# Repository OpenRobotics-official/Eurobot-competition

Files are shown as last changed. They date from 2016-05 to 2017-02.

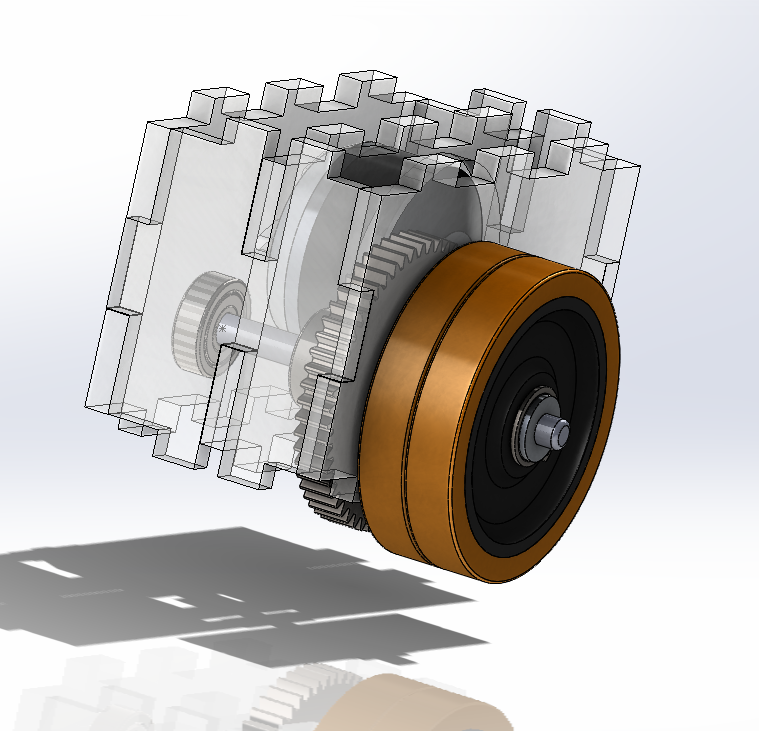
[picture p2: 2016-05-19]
wheelbase/Photo/wheelbase.PNG

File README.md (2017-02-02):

# Eurobot-competition

We are a team of 9 students from ECE Paris school of Engineering, building an Open Source platform for competition robots. We attended Eurobot France, Germany and UK.

## Usage and translation

As the license states, you can do anything you want with our files. We are in the process of checking the good translation of all files, so if you do not understand something, please message us.

## Instructions and logs

You can see how we did our project on our Hackaday.io [project](http://past.is/atcrt/). If you need any helpin using our files, feel free to contact us, **preferably on our hackaday project page**. It's one of our first Robotics project and it is far from perfect so we will be glad to hear some advice and criticism from any other teams.

### IRL - In Real Life

This is mostly meant to be a media for other teams to see what we have done in order to understand us and maybe help us at some competitions like the Île-de-France robotics cup. Feel free to ask questions and contact us IRL!

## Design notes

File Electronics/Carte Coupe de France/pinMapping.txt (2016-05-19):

composant	pin comp	pin arduino

stepper gauche	dir		41
		step		43

stepper droite	dir		37
		step		39

led red		+		52

lcd		data7		45
		data6		47
		data5		49
		data4		51
		enable		53

dip switch	1		36
		2		38
		3		40
		4		42

encodeur bas	X		21
		A		20
		B		19

encodeur haut	X		18
		A		2
		B		3

capteur		1		A5
		2		A4
		3		A3
		4		A2
		5		A1
		6		A0

servo-moteur	1		9
		2		10
		3		11
		5		13

Virage 90deg: 365 steps

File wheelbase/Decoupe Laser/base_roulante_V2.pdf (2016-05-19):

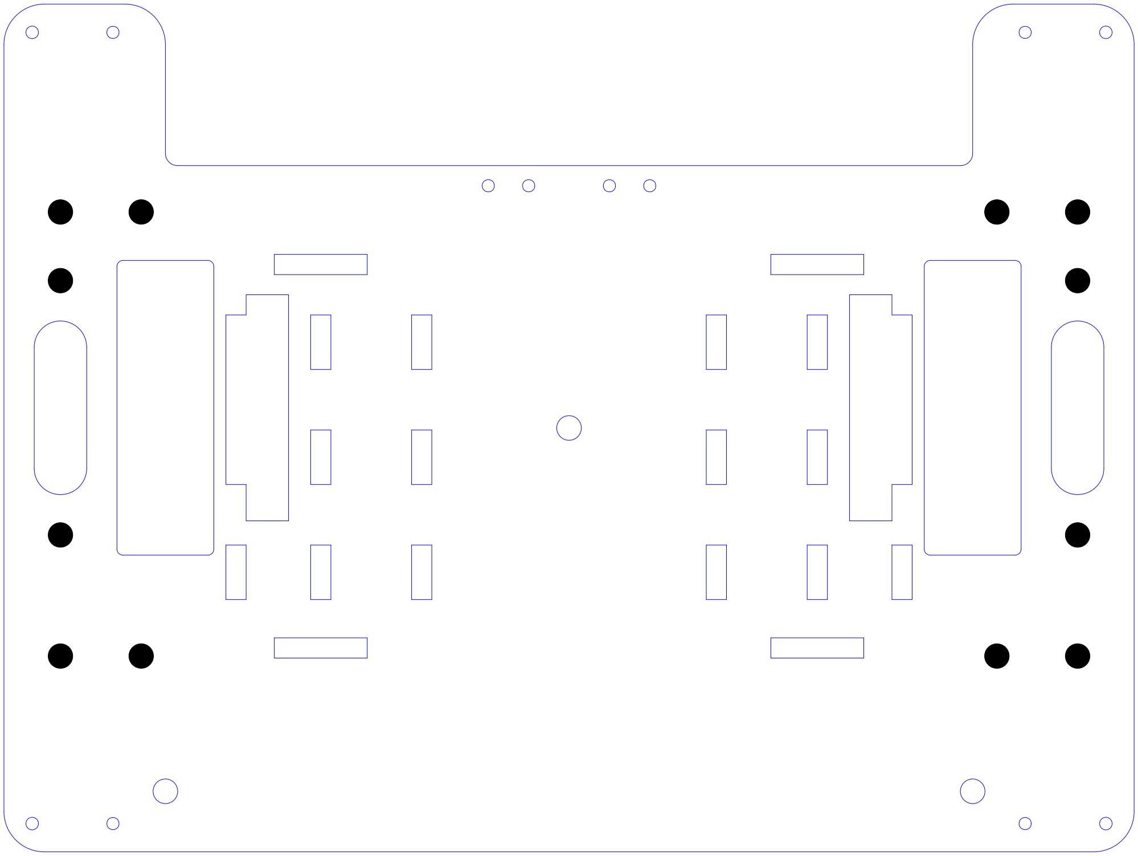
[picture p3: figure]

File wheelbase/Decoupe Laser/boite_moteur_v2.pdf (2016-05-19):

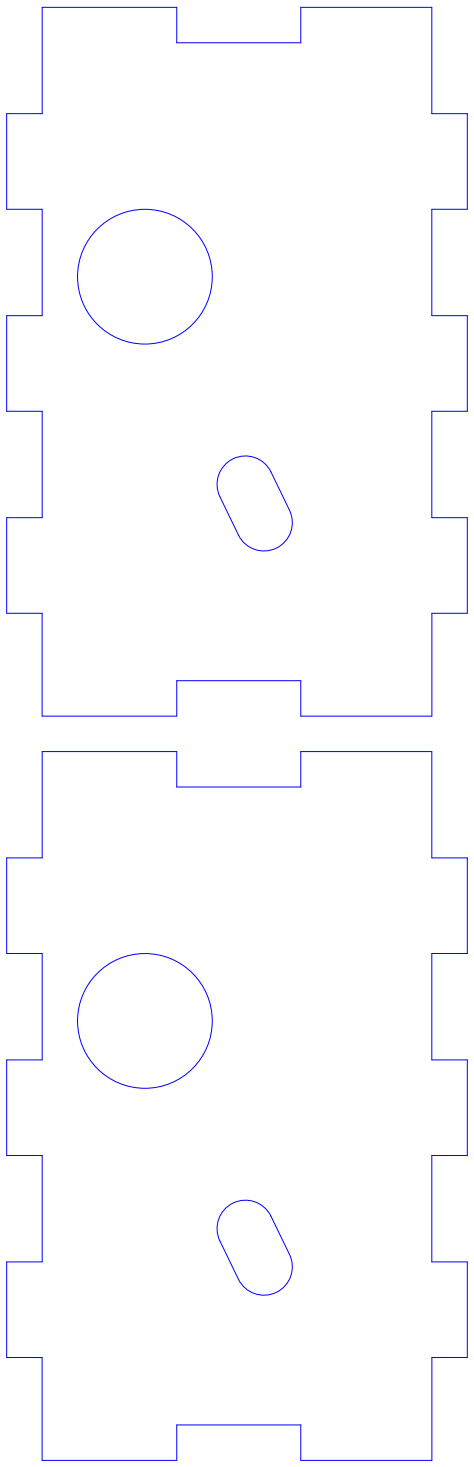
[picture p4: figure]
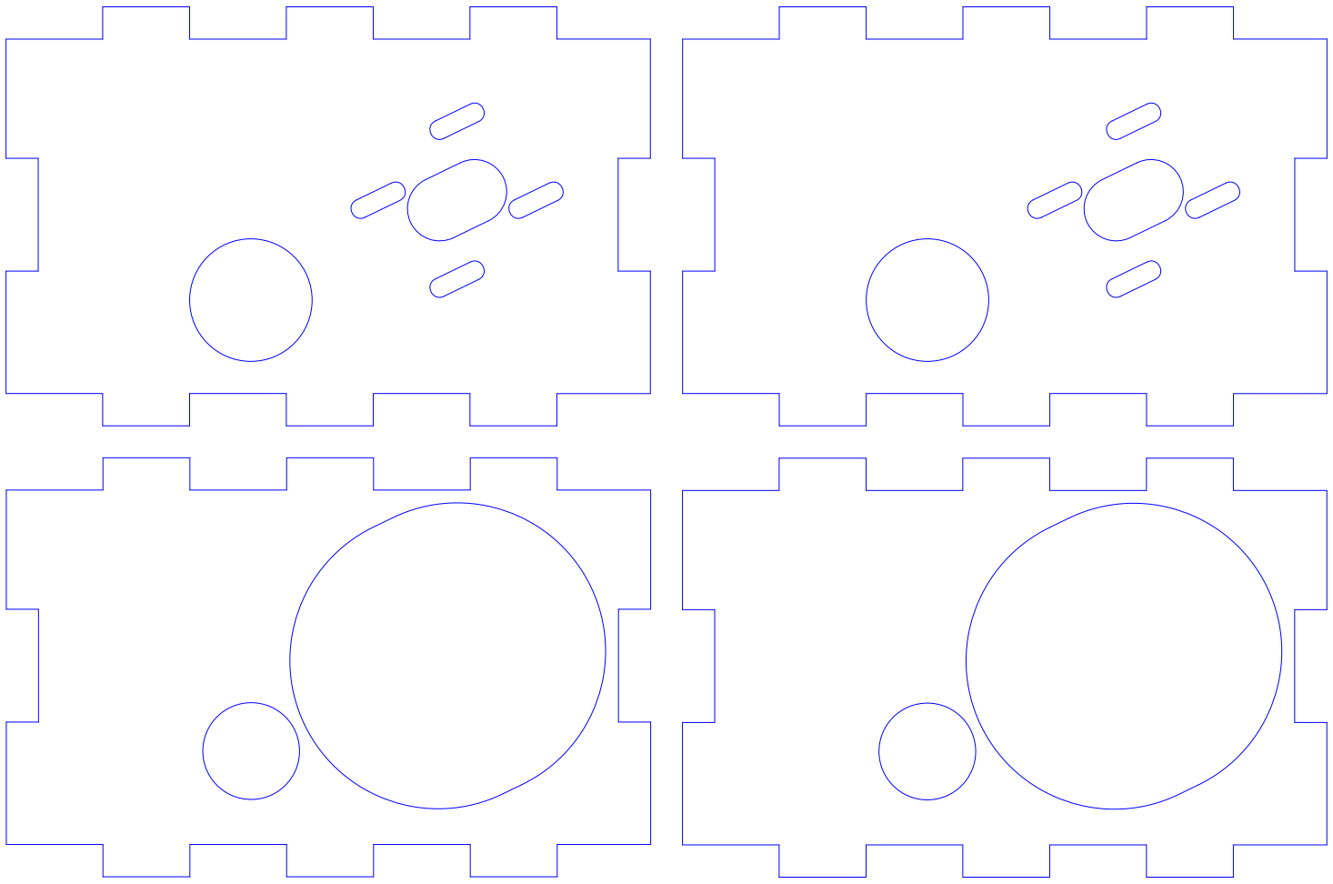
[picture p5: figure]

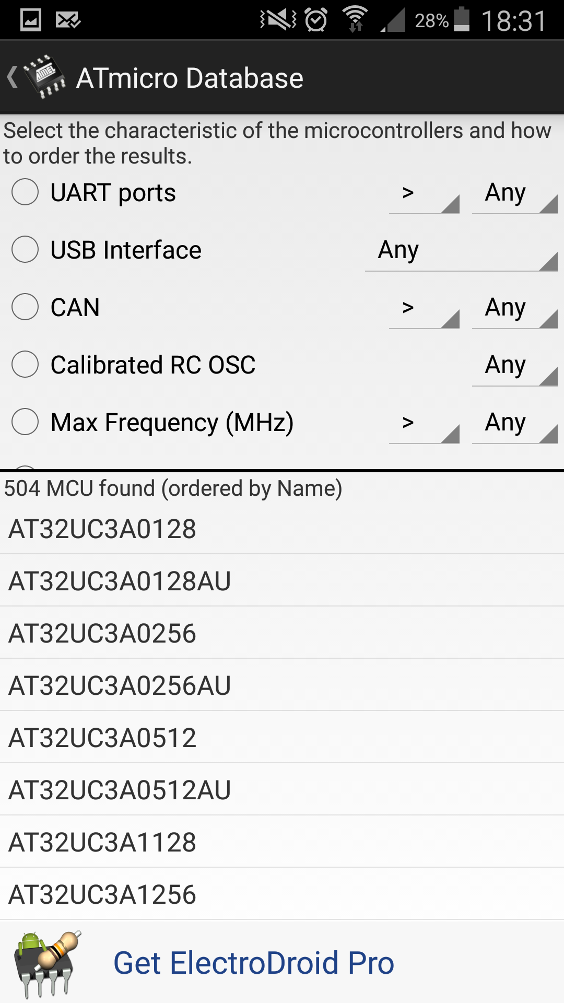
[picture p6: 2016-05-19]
Electronics/Microcontrôleur/Screenshot_2015-12-03-18-31-41.png

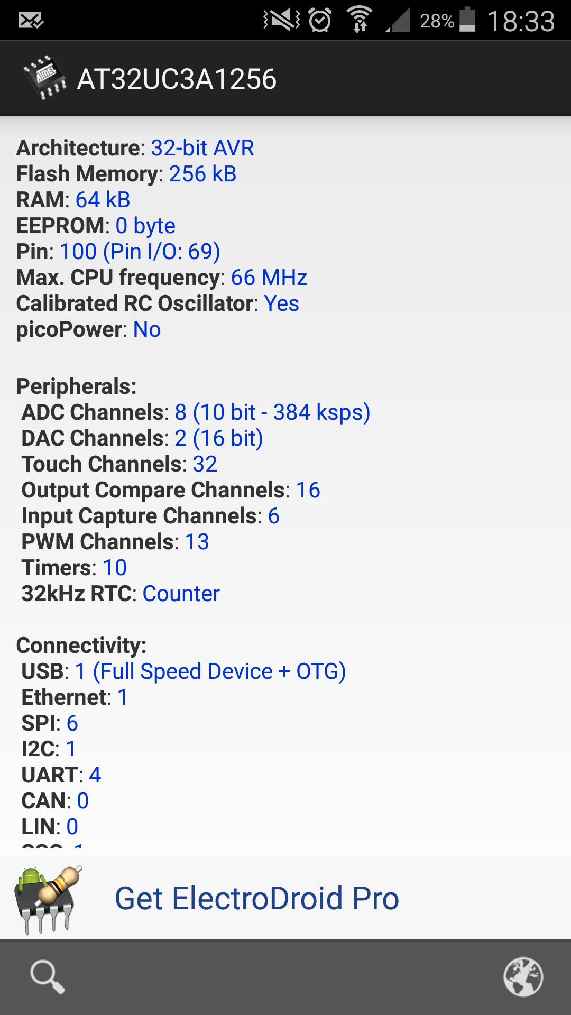
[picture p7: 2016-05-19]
Electronics/Microcontrôleur/Screenshot_2015-12-03-18-33-21.png

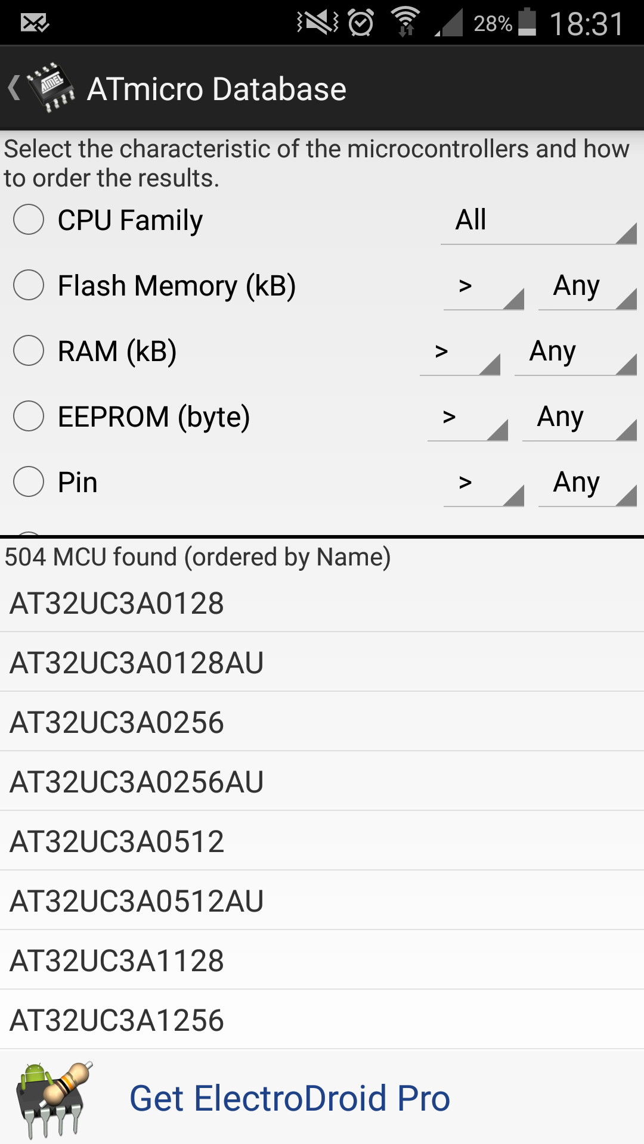
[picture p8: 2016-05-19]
Electronics/Microcontrôleur/Screenshot_2015-12-03-18-31-28.png

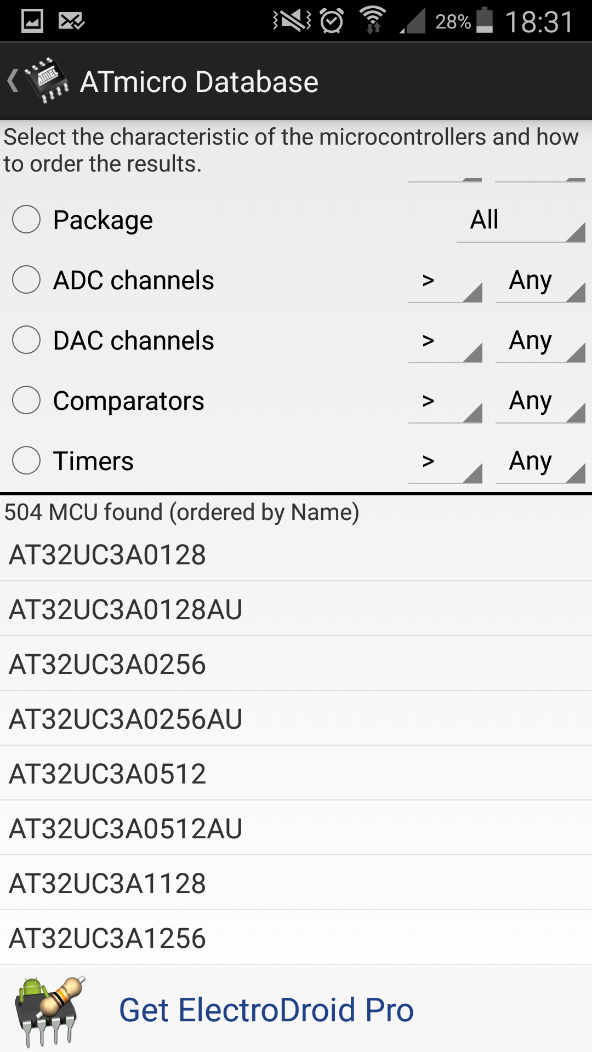
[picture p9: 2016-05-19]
Electronics/Microcontrôleur/Screenshot_2015-12-03-18-31-35.png

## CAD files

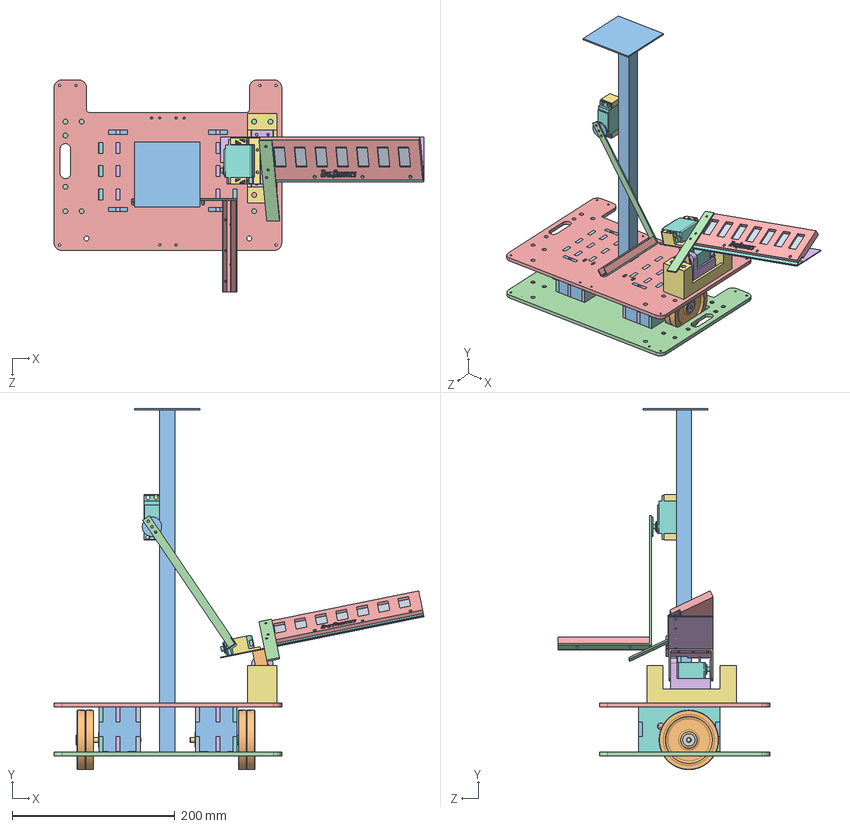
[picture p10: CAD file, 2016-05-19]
assembly_robot.SLDASM
454.7 x 444.0 x 261.1 mm
cote_support_moteur_fin x 2
outside ball bearing 6.6.19 x 6
inside ball bearing 6.6.19 x 6
Quanum360 base x 2
Quanum360 Cage x 2
cote_long_milieu x 2
tige-roue x 2
cote_long_roue x 2
T40H-SM62 x 2
BaneBots_T40 x 4
cote-court_50 x 4
base_dessous_V2_
base_dessus_V2_
Support_bras_base
Support_bras_bloc
Servo x 3
Support_bras_roulement
Support_bras_axe_rotatif
Accessoire_servo_rondelle x 2
Plaquette
Plaque_support_aimant
Plaque_support_poisson
support_servo x 2
Element_Charniere_metal x 2
Aimant x 7
inside_link_bearing
Profile_alu
Bar_angle
Bar_U

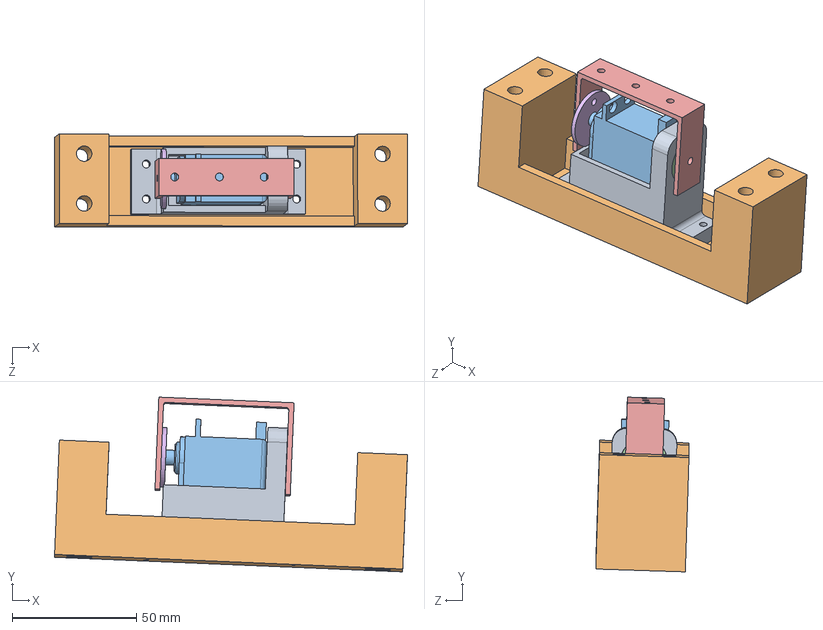
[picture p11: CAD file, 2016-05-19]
Fishing arm/Support_Bras.SLDASM
141.8 x 70.2 x 37.5 mm
Support_bras_base
Support_bras_bloc
Servo
Support_bras_roulement
Support_bras_axe_rotatif
Accessoire_servo_rondelle
inside_link_bearing

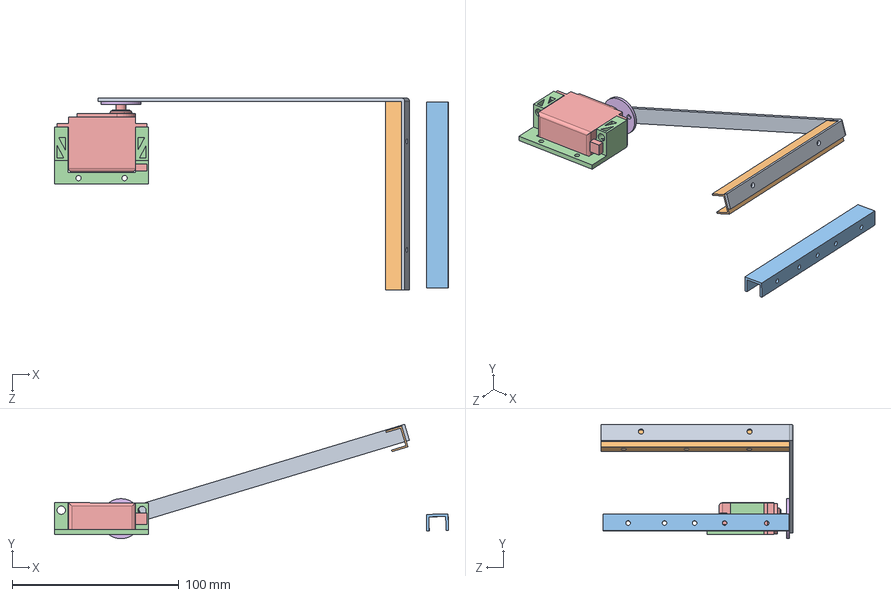
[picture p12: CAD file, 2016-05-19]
Funny action/Parasol_v2/Parasol_v2.SLDASM
236.0 x 68.5 x 115.0 mm
Bar_angle
Bar_U
Bar_u_robot
support_servo
Servo
Accessoire_servo_rondelle

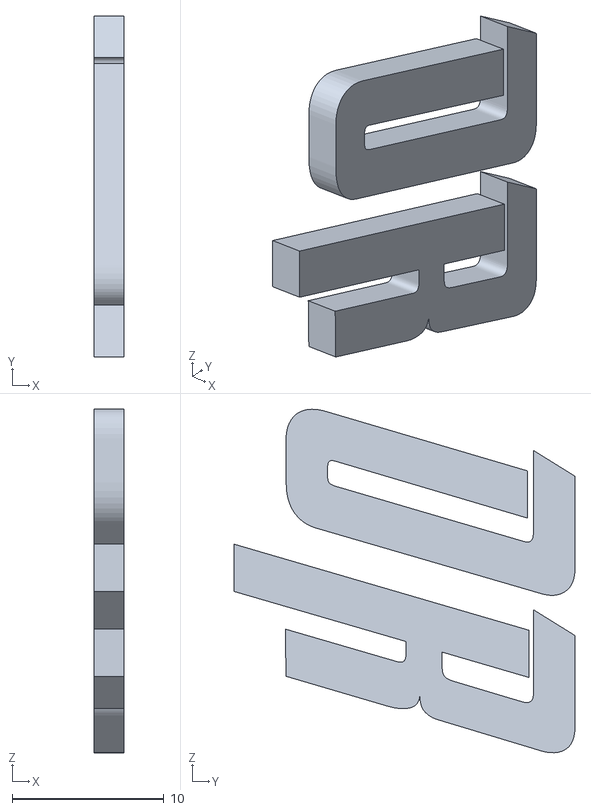
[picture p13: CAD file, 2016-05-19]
wheelbase/solidworks/STL/Assemblahe_base_stepper_logo - OR_logo_72_2mm-1.STL
2.00 x 22.5 x 22.7

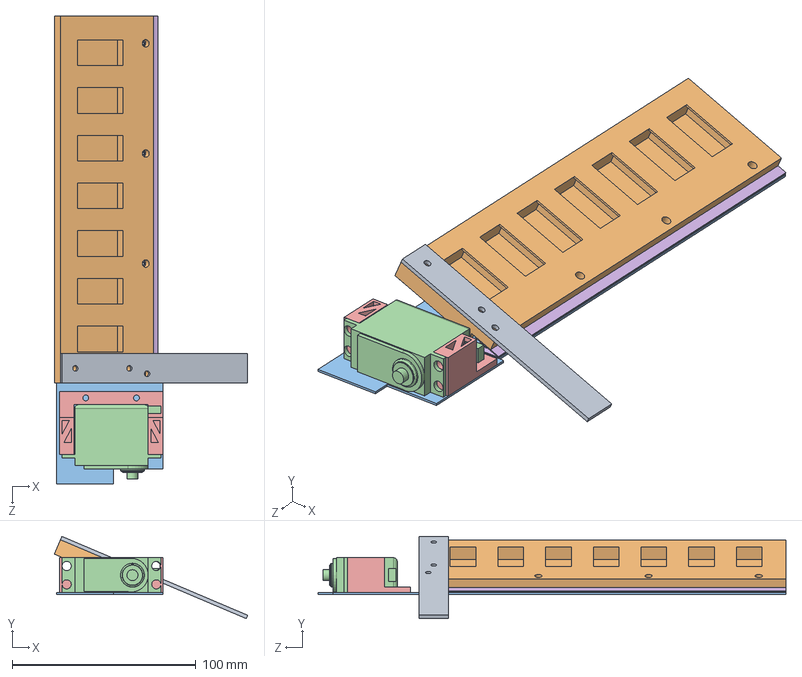
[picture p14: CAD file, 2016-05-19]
Fishing arm/Plaque_aimantée.SLDASM
105.4 x 44.8 x 255.0 mm
Plaquette
Plaque_support_aimant
Plaque_support_poisson
Servo
support_servo
Element_Charniere_metal x 2

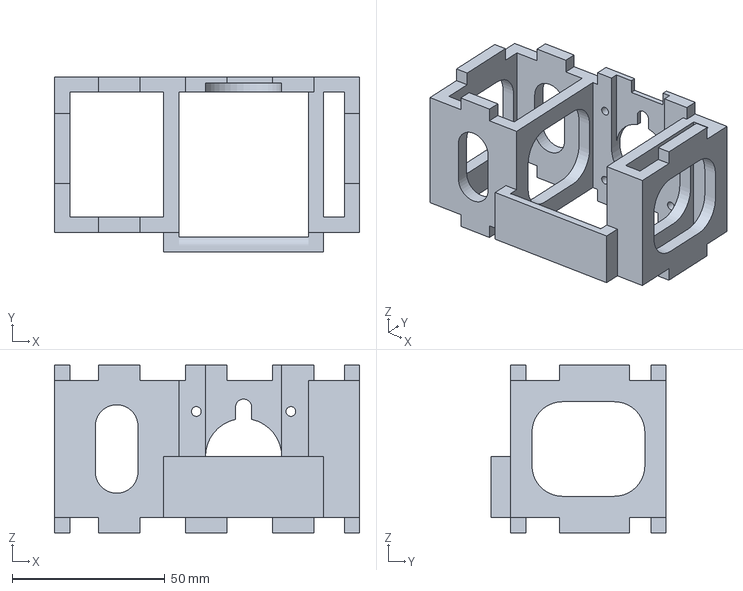
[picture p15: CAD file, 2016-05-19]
wheelbase/solidworks/STL/Assemblage_base_stepper_s3d.AMF
100.0 x 57.5 x 55.0 mm

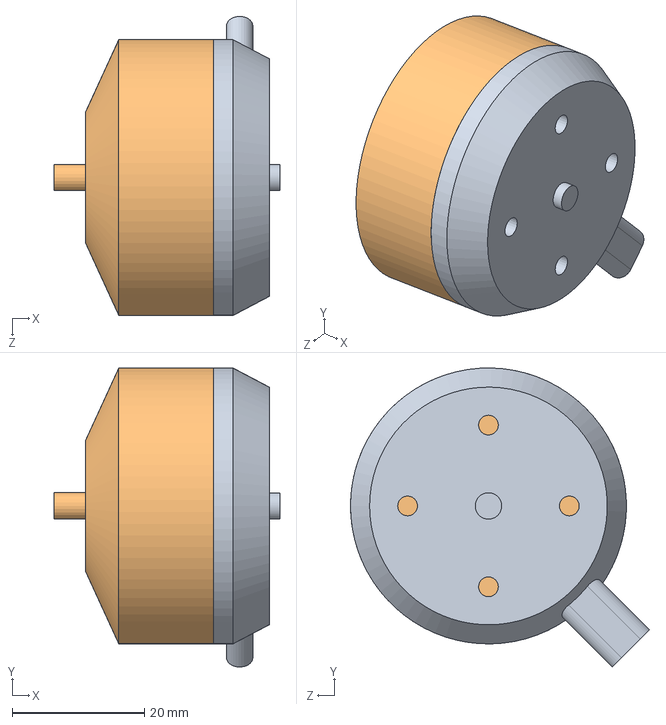
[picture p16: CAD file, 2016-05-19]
wheelbase/solidworks/Quanum motor.SLDASM
34.2 x 45.3 x 45.3 mm
Quanum360 base
Quanum360 Cage

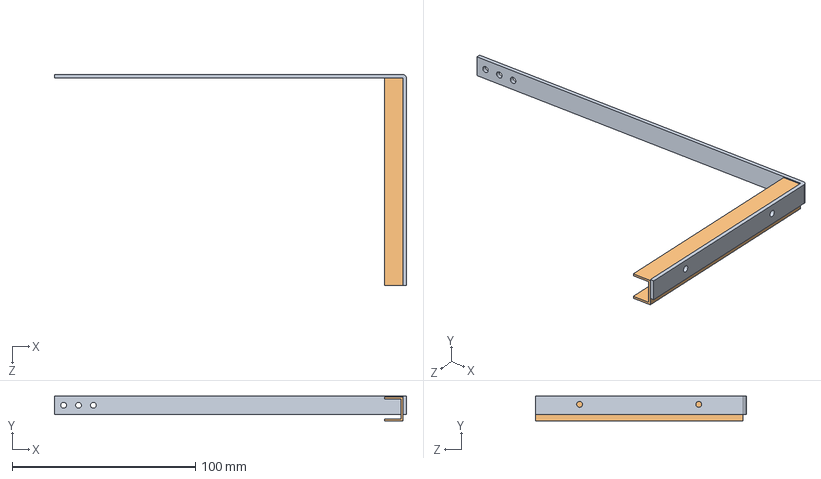
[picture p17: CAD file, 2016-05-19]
Funny action/Parasol_v2/Bras_principal_parasol.SLDASM
192.0 x 13.5 x 115.0 mm
Bar_angle
Bar_U

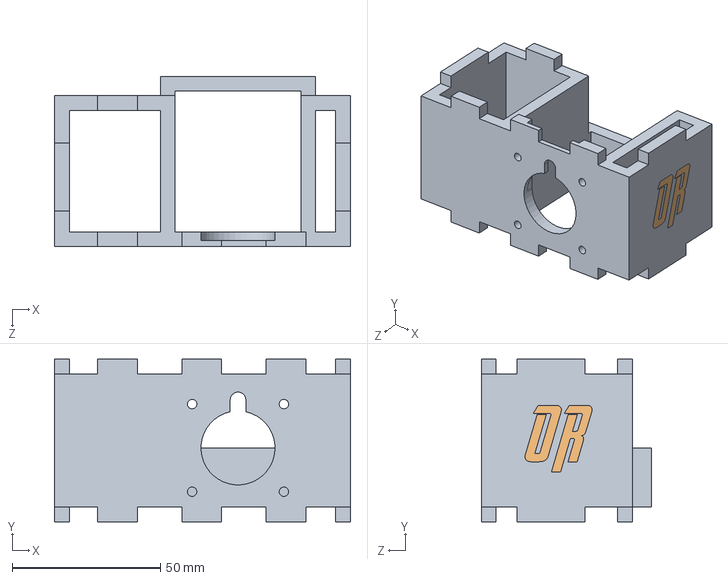
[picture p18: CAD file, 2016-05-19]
wheelbase/solidworks/Assemblahe_base_stepper_logo.SLDASM
100.0 x 55.0 x 57.5 mm
base_stepper
OR_logo_72_2mm

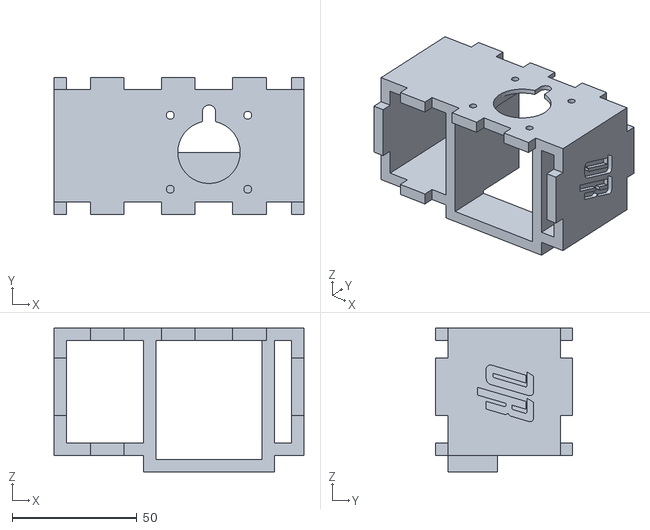
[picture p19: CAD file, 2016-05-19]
wheelbase/solidworks/STL/Assemblahe_base_stepper_logo - base_stepper-1-1.STL
100.0 x 55.0 x 57.5

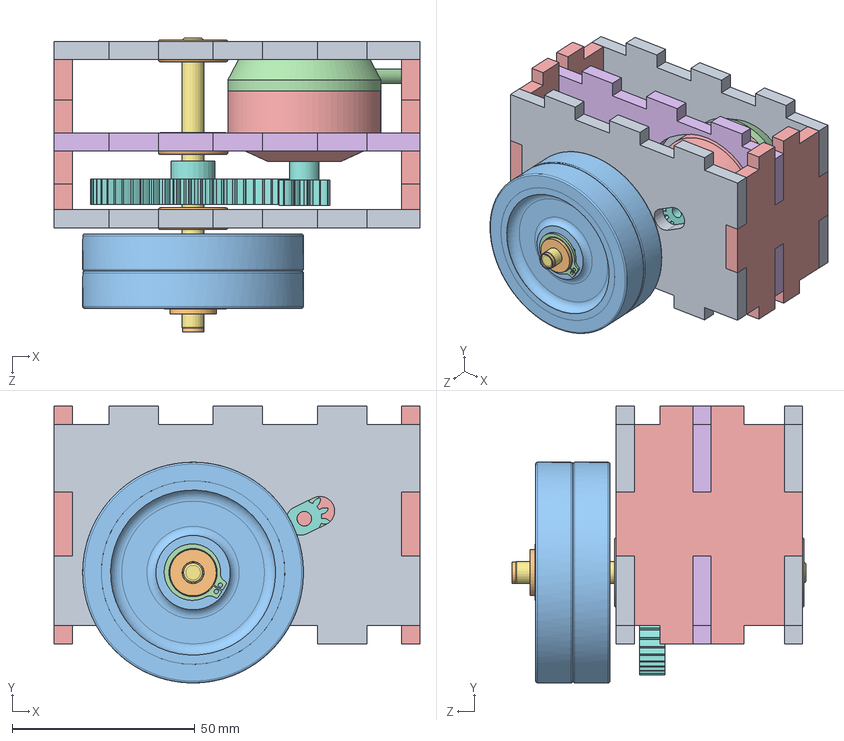
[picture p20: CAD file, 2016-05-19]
wheelbase/solidworks/Assemblahe_base_roulante.SLDASM
100.0 x 75.7 x 80.4 mm
cote_support_moteur_fin
outside ball bearing 6.6.19 x 3
inside ball bearing 6.6.19 x 3
Quanum360 base
Quanum360 Cage
cote_long_milieu
tige-roue
spur gear_am x 2
cote_long_roue
T40H-SM62
BaneBots_T40 x 2
basic external retaining ring_ai
cote-court_50 x 2

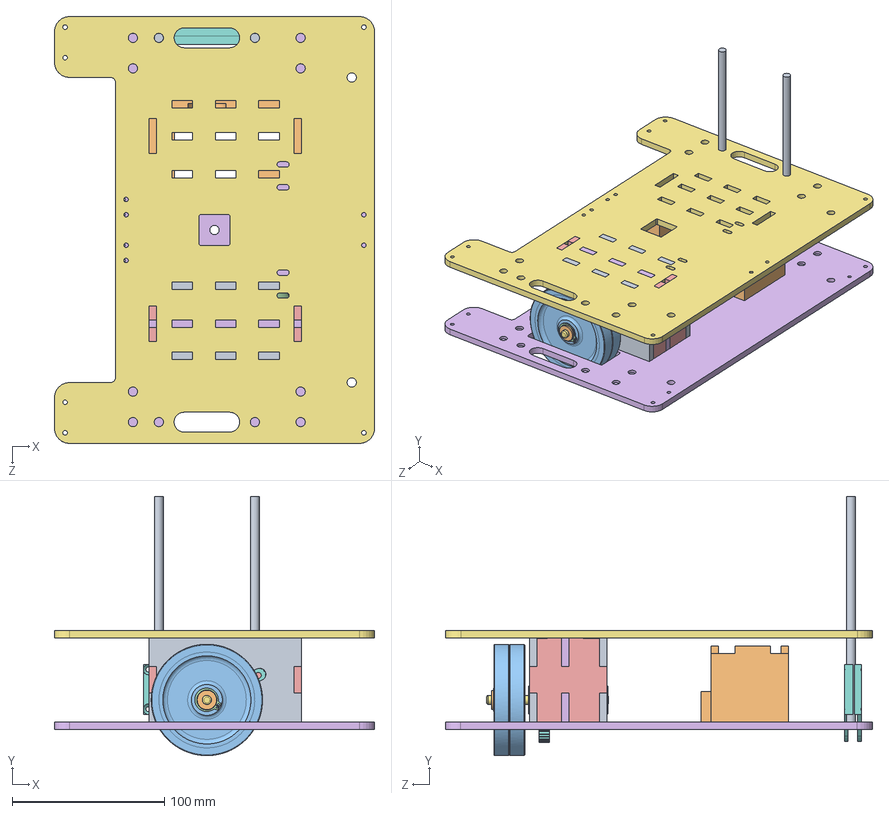
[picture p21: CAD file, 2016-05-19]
wheelbase/solidworks/Base roulante lucas/Assemblahe_base_roulante.SLDASM
210.0 x 170.0 x 280.0 mm
cote_support_moteur_fin
outside ball bearing 6.6.19 x 3
inside ball bearing 6.6.19 x 3
Quanum360 base
Quanum360 Cage
cote_long_milieu
tige-roue
spur gear_am x 2
cote_long_roue
T40H-SM62
BaneBots_T40 x 2
basic external retaining ring_ai
cote-court_50 x 2
base_dessous_V2_
base_dessus_V2_
U_plaque_codeur_v4 x 2
6mm_axle x 2
base_stepper

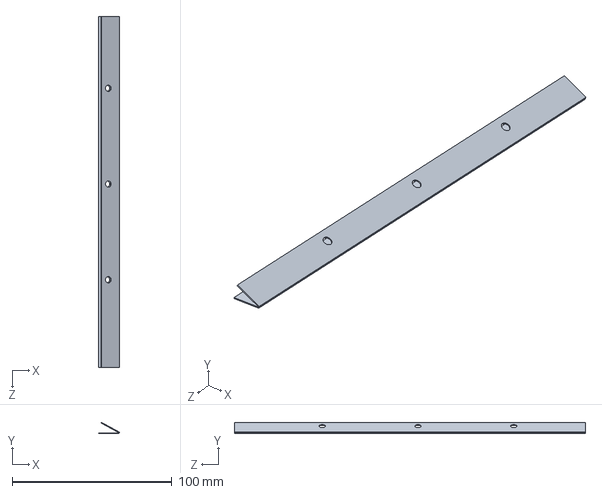
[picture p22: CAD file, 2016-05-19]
Fishing arm/Charniere.SLDASM
13.2 x 7.16 x 220.0 mm
Element_Charniere x 2

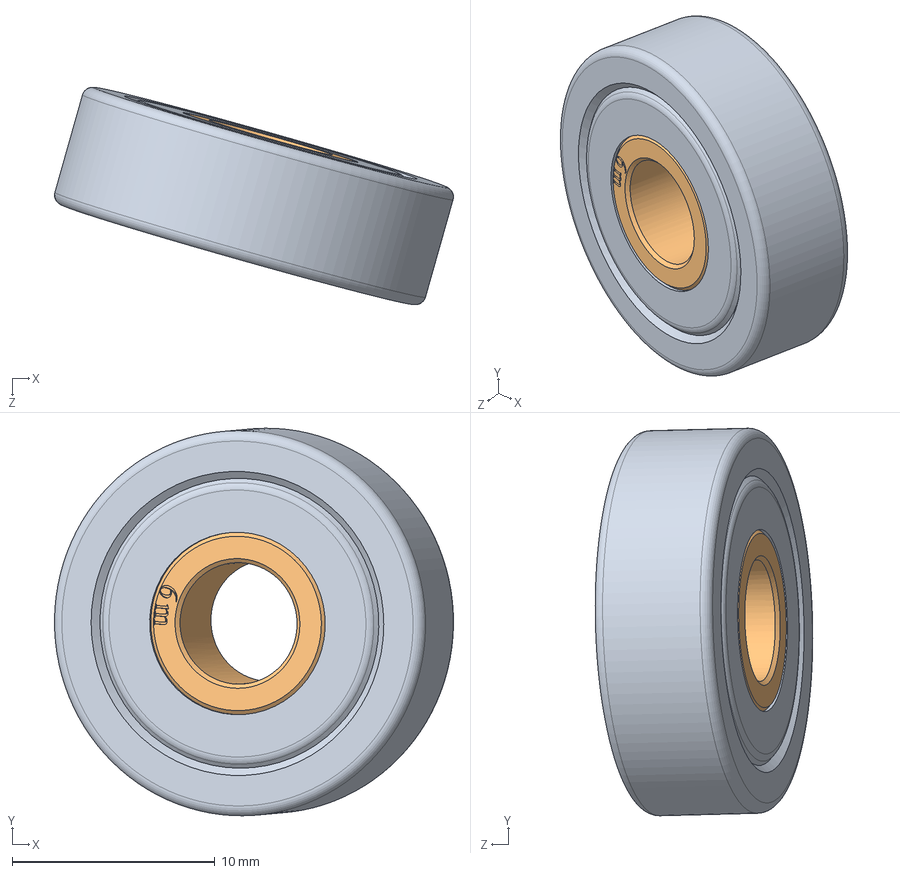
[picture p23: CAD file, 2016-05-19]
wheelbase/solidworks/Base roulante lucas/ball bearing.SLDASM
19.7 x 19.1 x 10.7 mm
outside ball bearing 6.6.19
inside ball bearing 6.6.19

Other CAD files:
wheelbase/solidworks/STL/Assemblahe_base_stepper_logo - OR_logo_72_2mm-1-1.STL
wheelbase/solidworks/STL/Assemblahe_base_stepper_logo - base_stepper-1.STL
wheelbase/solidworks/Base roulante lucas/Quanum motor.SLDASM
wheelbase/solidworks/Base roulante lucas/Banebots_double_T40.SLDASM
3D-others/STL/Support Tirette.STL
3D-others/STL/Support_axe_encondeurs.STL
3D-others/STL/Support_bille_folle.STL
3D-others/STL/Support_trepied.STL
3D-others/STL/support_plaque_sponsor.STL
3D-others/STL/tirette.STL
3D-others/Support Tirette.SLDPRT
3D-others/Support_axe_encondeurs.SLDPRT
3D-others/Support_bille_folle.SLDPRT
3D-others/Support_trepied.SLDPRT
3D-others/support_plaque_sponsor.SLDPRT
3D-others/tirette.SLDPRT
Fishing arm/Accessoire_servo_rondelle.SLDPRT
Fishing arm/Aimant.SLDPRT
Fishing arm/Charniere_metal.SLDASM
Fishing arm/Charniere_plastique.SLDPRT
Fishing arm/Element_Charniere.SLDPRT
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

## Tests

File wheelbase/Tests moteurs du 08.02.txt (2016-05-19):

Motors:
Maxon :
2A at 24V

Brushless 1850Kv, 10A controller
3A at 12V

Servo library: esc control between 50 and 150 /179
cutoff at 30 or less and 179. Brake levels: from low (50) => 93, from high (150) => 86

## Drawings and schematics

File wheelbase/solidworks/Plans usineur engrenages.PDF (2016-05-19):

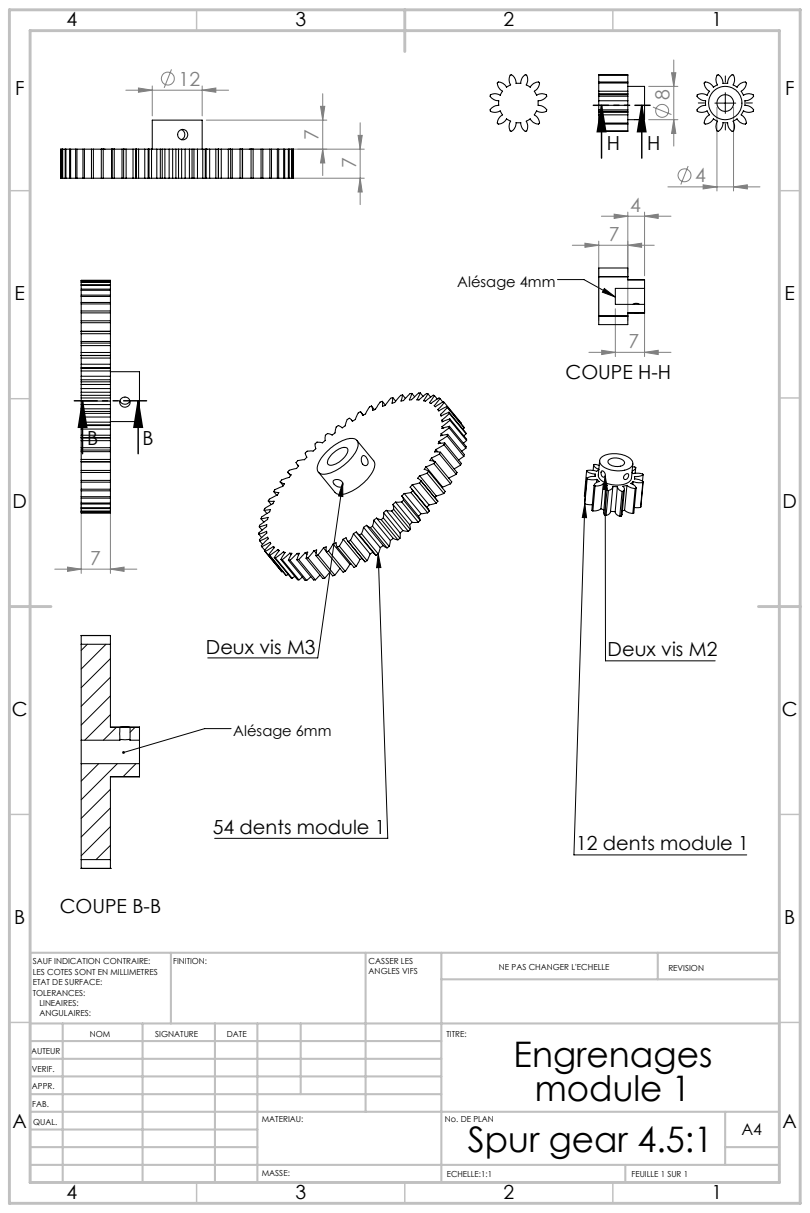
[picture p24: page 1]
COUPE B-B; Alésage 6mm; Deux vis M3; 54 dents module 1; COUPE H-H; Alésage 4mm; Deux vis M2; 12 dents module 1; FINITION:; CASSER LES; ANGLES VIFS; NE PAS CHANGER L'ECHELLE; REVISION; ECHELLE:1:1; FEUILLE 1 SUR 1

SAUF INDICATION CONTRAIRE:
LES COTES SONT EN MILLIMETRES
ETAT DE SURFACE:
TOLERANCES:
LINEAIRES:
ANGULAIRES:

NOM | SIGNATURE | DATE | | | | TITRE: Engrenages module 1

AUTEUR
VERIF.
APPR.
FAB.
QUAL. | | | | MATERIAU: | No. DE PLAN Spur gear 4.5:1 | A4

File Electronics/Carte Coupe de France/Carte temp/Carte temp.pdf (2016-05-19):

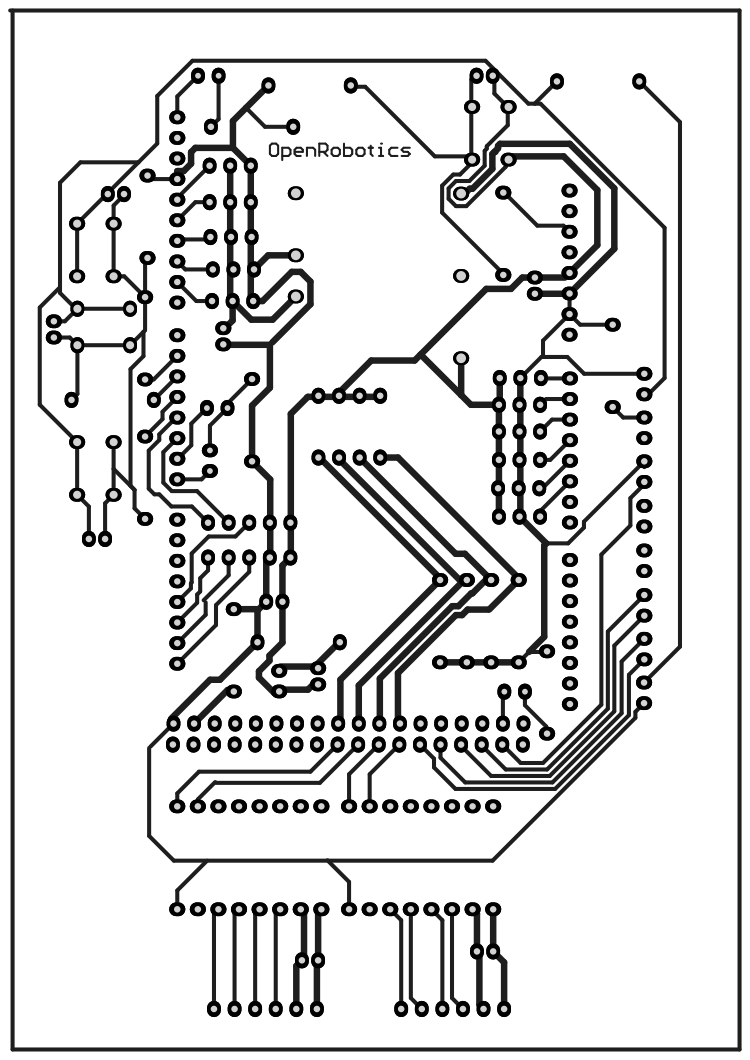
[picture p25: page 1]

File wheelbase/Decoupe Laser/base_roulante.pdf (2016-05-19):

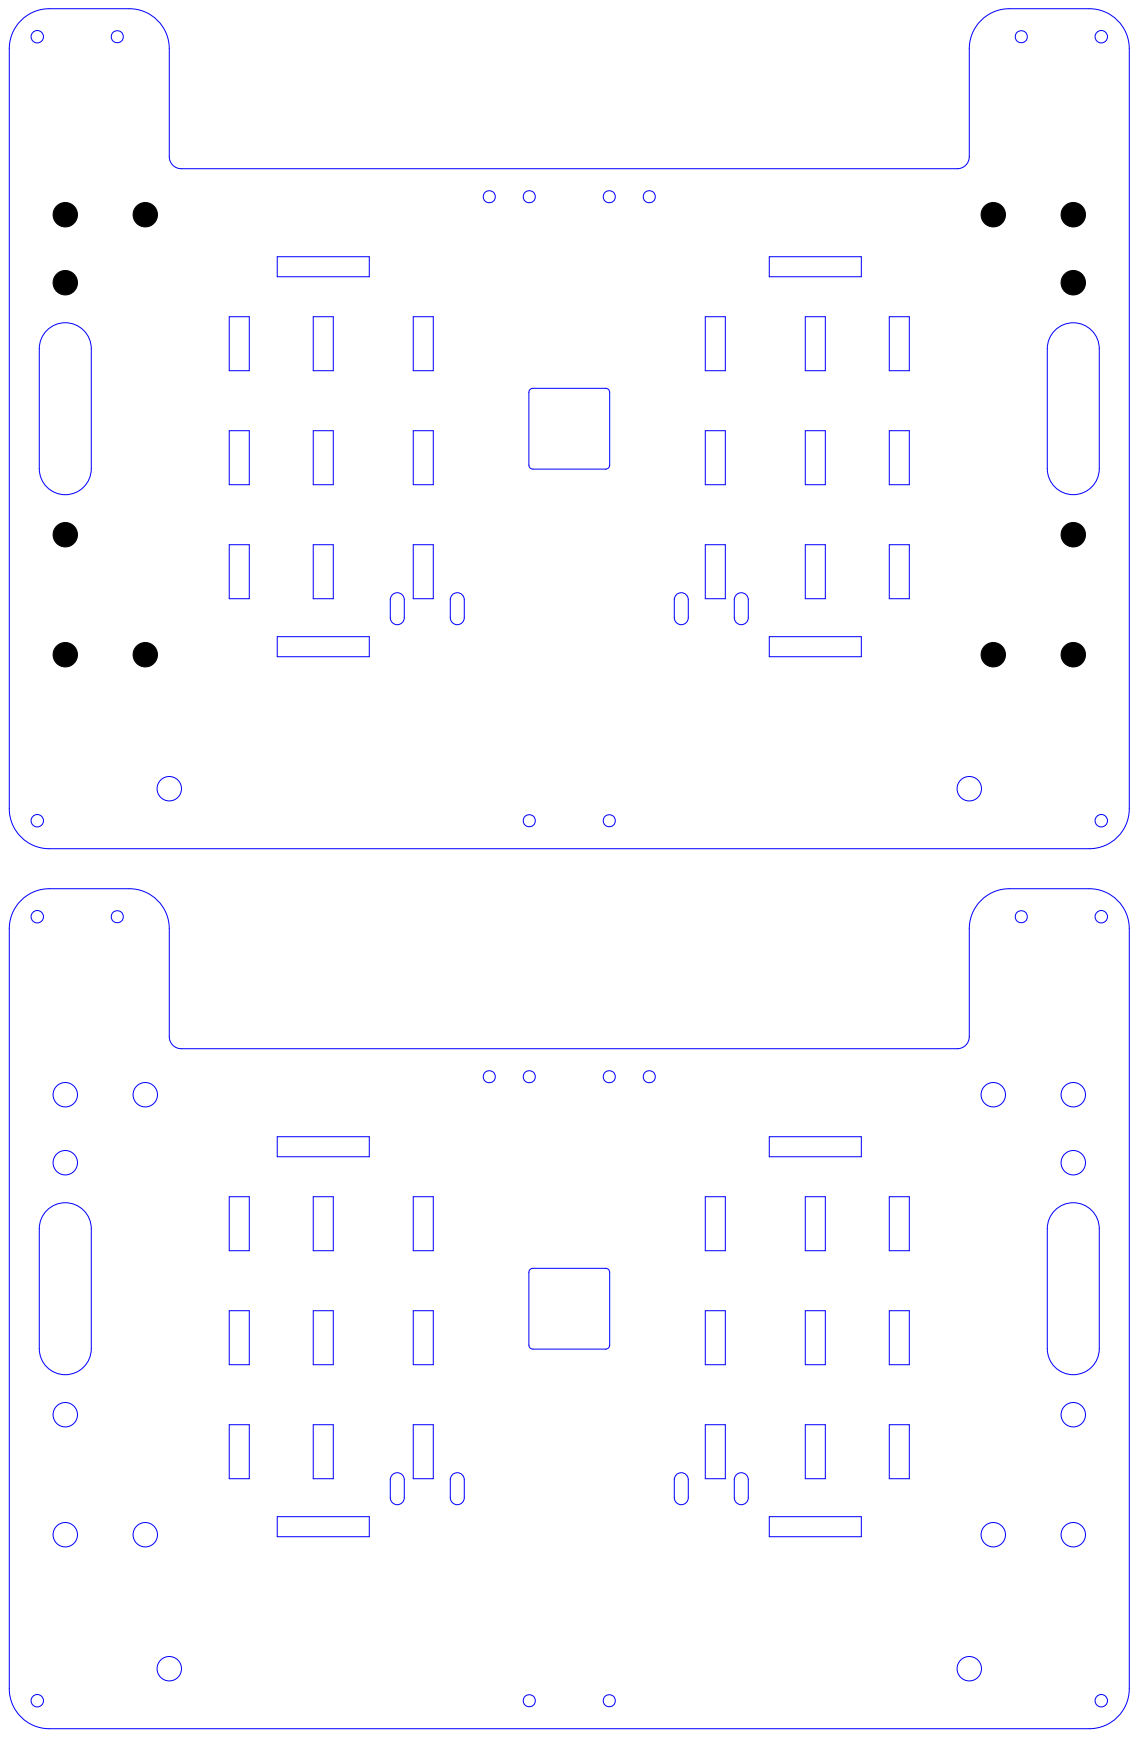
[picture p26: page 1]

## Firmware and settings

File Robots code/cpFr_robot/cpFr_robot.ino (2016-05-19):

 #include <Servo.h>
 #include <Arduino.h>
 #include "BasicStepperDriver.h"
 #include "A4988.h"


 #define encoder0PinA 20
 #define encoder0PinI 21
 #define encoder0PinB 19
 #define encoder1PinA 2
 #define encoder1PinI 18
 #define encoder1PinB 3
 #define tirette 32
 #define sharpread A1
 #define sharpread1 A2
 #define ticklength  0.226194
 #define pin_bras 11
 #define pin_releaseFish 10
 #define DIR0 41
 #define STEP0 43
 #define DIR1 37
 #define STEP1 39
 #define MICROSTEPS 1
 #define MOTOR_STEPS 400
 #define FW 1
 #define BK -1
 #define MAX_RPM 200




 A4988 stepper0(MOTOR_STEPS, DIR0, STEP0);
 A4988 stepper1(MOTOR_STEPS, DIR1, STEP1);
 Servo bras; //servo base fixe robot
 Servo releaseFish; //servo 
 Servo parasol;
        	 

volatile long int encoder0Pos = 0;
volatile int precEncoder0Pos = 0;
volatile int encoder0Turn = 0;
volatile long int encoder1Pos = 0;
volatile int precEncoder1Pos = 0;
volatile int encoder1Turn = 0;
volatile long int dist = 0;
volatile int angle = 0;

volatile int dir = 0;
volatile int dir1 = 0;


int begincount = 0;
volatile int count = 0;
int timer3_counter;

void setup()
{
  pinMode(pin_bras, OUTPUT);
  pinMode(pin_releaseFish, OUTPUT);
  
  parasol.attach(13);
  parasol.write(10);

  bras.attach(pin_bras);
  bras.write(180);
 
  releaseFish.attach(pin_releaseFish);
  releaseFish.write(180);

  // initialize timer1 
  noInterrupts();           // disable all interrupts
  TCCR3A = 0;
  TCCR3B = 0;

  // Set timer1_counter to the correct value for our interrupt interval
  timer3_counter = 3036;   // preload timer 65536-16MHz/256/2Hz
  TCNT3 = timer3_counter;   // preload timer
  TCCR3B |= (1 << CS12);    // 256 prescaler 
  TIMSK3 |= (1 << TOIE3);   // enable timer overflow interrupt
  interrupts();             // enable all interrupts

  
  stepper0.setRPM(200);
  stepper0.setMicrostep(MICROSTEPS);
  stepper1.setRPM(200);
  stepper1.setMicrostep(MICROSTEPS);

  pinMode(tirette , INPUT);
  pinMode(sharpread , INPUT);
  pinMode(sharpread1 , INPUT);
  /* 
  pinMode(encoder0PinB, INPUT); 
  pinMode(encoder0PinI, INPUT); 

  pinMode(encoder1PinA, INPUT); 
  pinMode(encoder1PinB, INPUT); 
  pinMode(encoder1PinI, INPUT); 

  attachInterrupt(0, initcount, CHANGE);/*
  attachInterrupt(1, resetEncoder0, RISING);
*/
  attachInterrupt(3, doEncoder0, CHANGE);
  attachInterrupt(1, doEncoder1, CHANGE);

  Serial.begin (9600);
}



void doEncoder0(){

  // look for a low-to-high on channel A
  if (digitalRead(encoder0PinA) == HIGH) { 

    // check channel B to see which way encoder is turning
    if (digitalRead(encoder0PinB) == LOW) {  
      encoder0Pos = encoder0Pos + 1*ticklength;         // CW
      dir = 0;
    } 
    else {
      encoder0Pos = encoder0Pos - 1;         // CCW
      dir = 1;
    }
  }

  
  Serial.println (encoder0Pos, DEC);          

}

void doEncoder1(){

  // look for a low-to-high on channel A
  if (digitalRead(encoder1PinA) == HIGH) { 

    // check channel B to see which way encoder is turning
    if (digitalRead(encoder1PinB) == LOW) {  
      encoder1Pos = encoder1Pos + 1*ticklength;         // CW
      dir = 0;
    } 
    else {
      encoder1Pos = encoder1Pos - 1;         // CCW
      dir1 = 1;
    }
  }

  
  Serial.println (encoder0Pos, DEC);          

}
/*
void resetEncoder0()
{
    //increment nb of turns
    if (dir == 0)
    {
      encoder0Turn = encoder0Turn + 1;
    }
    else if(dir == 1)
    {
      encoder0Turn = encoder0Turn - 1;
    }
    //reset position
    Serial.println ("turn");
    Serial.println (encoder0Turn, DEC);
}

void resetEncoder1()
{
    //increment nb of turns
    if (dir == 0)
    {
      encoder1Turn = encoder1Turn + 1;
    }
    else if(dir == 1)
    {
      encoder1Turn = encoder1Turn - 1;
    }
    //reset position
    Serial.println ("turn");
    Serial.println (encoder1Turn, DEC);
}
*/

ISR(TIMER3_OVF_vect)        // interrupt service routine 
{
  TCNT3 = timer3_counter;
  if (count < 90 && begincount != 0)
  {
    count = count + 1;// preload timer
    //Serial.println (count, DEC);

  }
  dist = (encoder0Pos + encoder1Pos)/2;
  angle = encoder0Pos - encoder1Pos;
 


        
       
 // speed and acceleration encoder 0
// encoder0Speed = encoder0Pos*10 - precEncoder0Pos;
 //precEncoder0Pos = encoder0Pos;
 //encoder0Acc = encoder0Speed - precEncoder0Speed;
 //precEncoder0Speed = encoder0Speed;

 //1 tick = 0.226194

    /*Serial.println ("speed");
    Serial.println (encoder0Speed, DEC);

    Serial.println ("acc");
    Serial.println (encoder0Acc, DEC);*/

 
}



void fish(int k)
{
  if(k==0) //position initiale du bac poisson = arrivée au bac poisson
  {
    //Stop robot
    bras.write(110);
    //Redémarrage du robot
  }
  if(k==1) //position finiale  du bac poisson
  {
    //Stop robot
    bras.write(145);
    //Redémarrage du robot
  }
  if(k==2) // decrochage au dessus du filet
  {
    //Stop robot
    bras.write(110);
    delay(300);
    releaseFish.write(100);
    delay(1000);
    releaseFish.write(180);
    delay(300);
    bras.write(180);
    //Redémarrage du robot
  } 
}


void stepperGoto(int rsteps) {
  int steps = abs(rsteps);
  int vDouille=0;

  for (int i=0; i<steps; ++i) {
    if (i>steps*0.2) {
      //rpm = rpm + i/( steps*STEPS_TO_CM*MAX_RPM*spd/100 
      stepper0.setRPM( 200);
      stepper1.setRPM( 200 );
      if (i>steps*0.4) {
        stepper0.setRPM( 200 );
        stepper1.setRPM( 200 );
    
        if (i>steps*0.6) {
          //rpm = rpm - rpm*(i - (1/3)*steps*STEPS_TO_CM)/( ( (2/3)*steps*STEPS_TO_CM ) );
          stepper0.setRPM( 200 );
          stepper1.setRPM( 200 );
    
          if (i>steps*0.8) {
            //rpm = rpm - rpm*(i - (1/3)*steps*STEPS_TO_CM)/( ( (2/3)*steps*STEPS_TO_CM ) );
            stepper0.setRPM( 200 );
            stepper1.setRPM( 200 );
          }
        }
      }
    }
    vDouille=0;
    while((analogRead(sharpread)>400 && rsteps > 0)) {
      if(!vDouille) {
            stepper0.setRPM( 70 );
            stepper1.setRPM( 70 );

            stepper0.move( 50 );
            stepper1.move( 50 );

            vDouille = 1;
            delay(500);

      }
    }
      while(analogRead(sharpread1)>400 && rsteps <0) {
      if(!vDouille) {
            stepper0.setRPM( 70 );
            stepper1.setRPM( 70 );

            stepper0.move( -50 );
            stepper1.move( -50 );

            vDouille = 1;
            delay(500);
        }
      }

    stepper0.move( (rsteps/steps)*FW );
    stepper1.move( -FW*(rsteps/steps) );
  }
}

void turnplus (int endturnplus)
{
  while(angle <= endturnplus)
  {
    if(digitalRead(sharpread)<80)
    {
      stepper0.move(1);
      stepper1.move(-1);
    }
  }
}

void turnminus (int endturnminus)
{
  while(angle >= endturnminus)
  {
    if(digitalRead(sharpread)<80)
    {
      stepper0.move(-1);
      stepper1.move(1);
    }
  }
}


void loop()
{



  int side = digitalRead(36);         /** SELECT SIDE HERE, 
               						 0 FOR GREEN, 1 FOR PURPLE **/



 if(begincount == 0 && digitalRead(tirette))
  {
    begincount = begincount + 1;
  }

  if (begincount == 0)
  {
      count = 0;
  }
  else
    {
    if (begincount == 1)
    {
      

      /** Blocks pushing movement **/     
      
      stepperGoto(900); //Move front  
      delay(200);
    if (side == 1)
    {
	    turn(45, side);   // Slite turn to push blocks in zone 
	   	delay(200);
	    stepperGoto(400);  //Push blocks
	      delay(200);
	      stepperGoto(400);  //Push blocks
	      delay(200);
	      turn(55, side); 
	      delay(200);
	      stepperGoto(400);  //Push blocks
	      delay(200);
    }
      if (side == 0)
    {
		turn(55, side);   		// Slite turn to push blocks in zone 
		delay(200);
		stepperGoto(400); //Push blocks
		delay(200);
		turn(55, side);   // Correction turn
		delay(200);
		stepperGoto(300); //Push blocks
		delay(200);
		turn(56, side);   // Correction turn 
		delay(200);
		stepperGoto(250); //Push blocks
		delay(200);
	   // Correction turn 
		stepperGoto(400); //Push Blocks
		  delay(200);
		  turn(-85, side);
		 stepperGoto(800);
    }
      
      stepperGoto(-3200); //Move back on towel
      delay(500);
      

      /** Cabin door movement **/
      
      stepperGoto(645);   //Slitly foward
      delay(500);
      if(side == 1)
      {
        turn(375, side);    // Turn 90deg to face backward the cabins 
        delay(100);
        stepperGoto(-2400);   // Backward movement to the cabin
        delay(200); 
      }
      if(side == 0)
      {
        turn(335, side);    // Turn 90deg to face backward the cabins 
        delay(100);
        stepperGoto(-2400);   // Backward movement to the cabin
        delay(200); 
      }
      
      // Check 1
      stepperGoto(300);   
      delay(200);
      stepperGoto(-800);    
      delay(200);

      // Check 2
      stepperGoto(500);   
      delay(200);
      if(side == 0)
      {
            //recalage entre les deux tentatives de portes
        turn(-375, side);
        delay(200); 
        stepperGoto(-900);
        delay(200);
        stepperGoto(800); 
        delay(200);
        turn(335, side);

      }
      if(side == 1)
      {
        //recalage entre les deux tentatives de portes
        delay(200); 
        turn(-335, side);
        delay(200); 
        stepperGoto(-800);
        delay(200);
        stepperGoto(800); 
        delay(200);
        turn(375, side);
      }

      // Check 3
      stepperGoto(-1000);   
      delay(200);

      /** Recadrage **/
      
      stepperGoto(500);
      delay(200);
      if(side == 1)
      {
        turn(375, 0);   // Turn 90deg to face backward the start 
        delay(100);
        stepperGoto(-1200);   
        delay(200); 
      }
      if(side == 0)
      {
        turn(335, 1);   // Turn 90deg to face backward the start 
        delay(100);
        stepperGoto(-1200);   
        delay(200); 
      }



      /** Fish movement**/
      
      stepperGoto(645);   //Slitly foward
      delay(200);
      if(side == 1)
      {
        turn(375, side);    // Turn 90deg to face frontward  the fish
        delay(100);
        //stepperGoto(-2100);   
        //delay(200); 
      }
      if(side == 0)
      {
        turn(335, side);    // Turn 90deg to face 'frontward the fish' 
        delay(100);
        //stepperGoto(-2100);   
        //delay(200); 
      }
      stepperGoto(3700);    // To the fish, frontward movement
      delay(200);

      stepperGoto(-220);
      delay(200);
      turn(370, 1);     // 
      delay(200);

      
      //fish(0);          // Drop the fish catcher								/// Fish Function

      delay(100);
      

      
      if (side == 0)
      {
      	//fish(0);																/// Fish Function
        stepperGoto(-500);
        delay(200);
        stepperGoto(700);
        delay(200);
      }

      if (side == 1)
      {
      	//fish(0);																/// Fish Function
        stepperGoto(500);
        delay(200);
        stepperGoto(-700);
        delay(200);
      }

     //fish(1);        														/// Fish Function

      if (side == 0)
      {
        stepperGoto(700);
        delay(200);
      }

      if (side == 1)
      {
        stepperGoto(-700);
        delay(200);
        
      }

     // fish(2);          // Release tthe fishs									/// Fish Function
      delay(200);
    
    
    
      /** Coquillqge test **/

      /*
      stepperGoto(400);
      delay(200);
      //turn(725, side);  
      turn(375, side);
      delay(50);
      turn(375, side);  
      delay(250);
      stepperGoto(200);*/

      // RAJOUTER FUNNY ACTION?


      //stepperGoto(-4000);
      //delay(5000);
      //stepperGoto(-2000);
      ///bras.write(90);
      
   //action du robot
    while(1){
    	if (count == 90)
        {
        	 
  		
          //moteur1.write(90);
          //moteur2.write(90);
          	//bras.write(180);

          	
            parasol.write(150);
        }
            


        }
      }
  }

  }


void turn(int steps, unsigned char side)
{
  int abs_steps = abs(steps);
  if (side == 0)    // To be modified
  {
    for(int i=0; i<abs_steps; i++)
    {
        stepper0.setRPM(150);
        stepper1.setRPM(150);
        stepper0.move( (steps/abs_steps)*FW );
      stepper1.move( FW*(steps/abs_steps) );
    }
    
  }
  if (side == 1)    // To be modified
  {
    for(int i=0; i<abs_steps; i++)
    {
        stepper0.setRPM(150);
        stepper1.setRPM(150);
        stepper0.move( (steps/abs_steps)*(-FW) );
      stepper1.move( -FW*(steps/abs_steps) );
    }
    
  }
} 

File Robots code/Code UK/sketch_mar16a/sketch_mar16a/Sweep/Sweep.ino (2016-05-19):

// Sweep
// by BARRAGAN <http://barraganstudio.com> 
// This example code is in the public domain.


#include <Servo.h> 
 
Servo parasol;
Servo bras;// create servo object to control a servo 
                // a maximum of eight servo objects can be created 
 
int pos = 0;    // variable to store the servo position 
 
void setup() 
{ 
  parasol.attach(9);  // attaches the servo on pin 9 to the servo object
  bras.attach(10);
  
} 
 
 
void loop() 
{ 
  for(pos = 0; pos < 180; pos += 1)  // goes from 0 degrees to 180 degrees 
  {                                  // in steps of 1 degree 
    parasol.write(pos);
    bras.write(pos);    // tell servo to go to position in variable 'pos' 
    delay(15);                       // waits 15ms for the servo to reach the position 
  } 
  for(pos = 180; pos>=1; pos-=1)     // goes from 180 degrees to 0 degrees 
  {                                
    parasol.write(pos);
    bras.write(pos);    // tell servo to go to position in variable 'pos' 
    delay(15);                       // waits 15ms for the servo to reach the position 
  }
} 
